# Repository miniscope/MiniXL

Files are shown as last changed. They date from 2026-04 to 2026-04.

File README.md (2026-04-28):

# MiniXL — Miniscope Extra Large FOV

The MiniXL is the second generation of the MiniLFOV, a large field-of-view miniature microscope for imaging neuronal activity in freely moving mice and larger animals. It supports deep brain imaging using implanted optical probes and cortical imaging through cranial windows.

## Features

- 3.5 mm field of view
- ~3 um resolution
- 1.9 mm working distance
- +/-200 um electronic focal adjustment
- Modular, achromatic optics
- 3.5 grams
- 30 mm tall
- Absolute head orientation sensor
- Single coaxial cable (down to 0.3 mm diameter) for power, communication, and data
- No soldering required

## Repository Structure

```
pcb/                PCB designs (KiCad)
  rigid-flex/       Main rigid-flex PCB assembly
    fabrication/    Gerber and drill files for manufacturing
optics/             Optical design (Zemax) source files
  plots/            Standardized output plots (MTF, spot diagrams, etc.)
housing/            3D printed microscope body
baseplate/          Head-mount baseplate
assets/             Images and resources for documentation
wiki.yml            Top-level metadata; per-component wiki.yml files in each subdir
                    are picked up by wiki-repo-bridge and synced on release tags.
```

## How to Cite

If you use the MiniXL in your research, please cite:

> Zhao, P., Guo, C., Xie, M., Chen, L., Golshani, P., & Aharoni, D. MiniXL: An open-source, large field-of-view epifluorescence miniscope enabling single-cell resolution and multi-region imaging in mice. *Science Advances*, 11(24), eads4995, 2025. DOI: [10.1126/sciadv.ads4995](https://doi.org/10.1126/sciadv.ads4995)

A BibTeX entry is available in [CITATION.bib](CITATION.bib).

## License

See [LICENSE](LICENSE) for details.

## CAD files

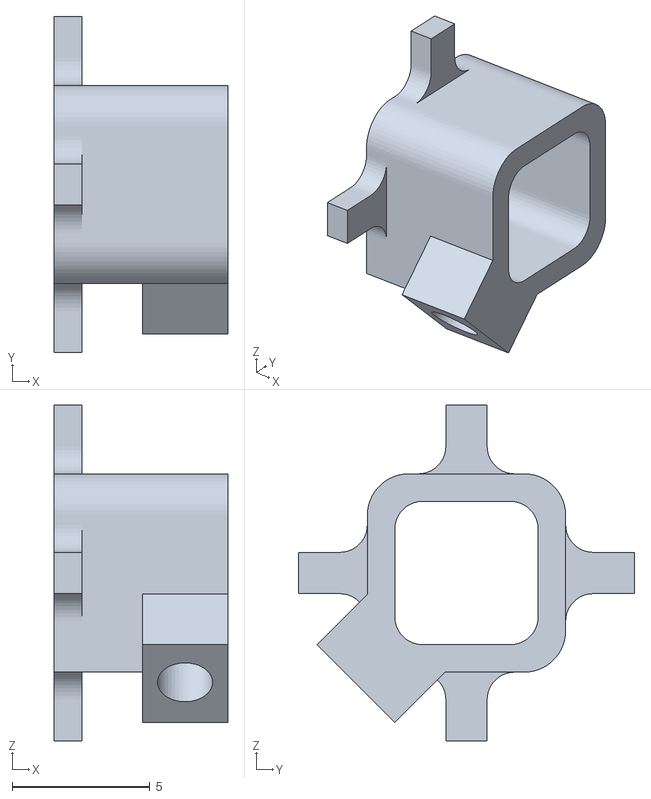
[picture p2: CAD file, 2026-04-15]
baseplate/fabrication/MiniXL_baseplate.stl
6.30 x 12.2 x 12.2

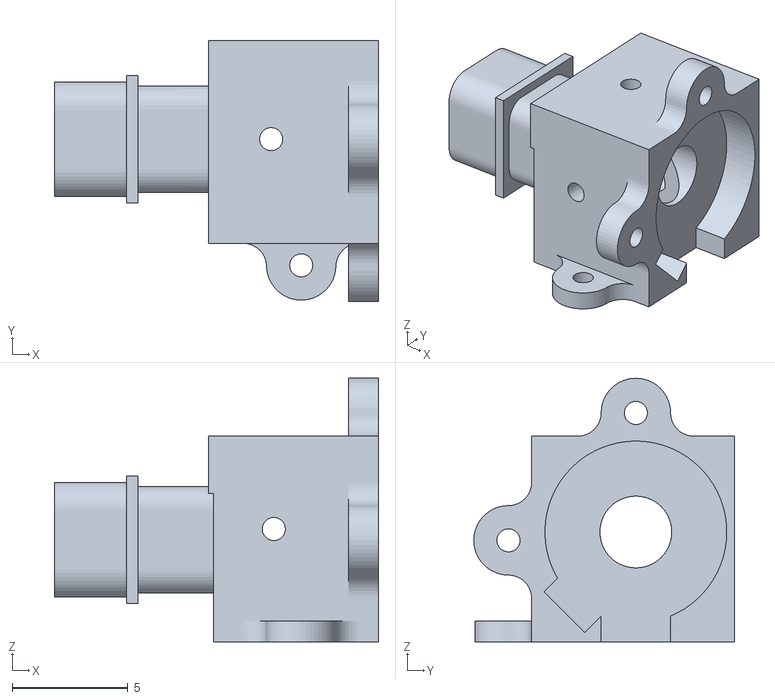
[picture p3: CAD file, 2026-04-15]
housing/fabrication/MiniXL_bottom.stl
14.0 x 11.2 x 11.4

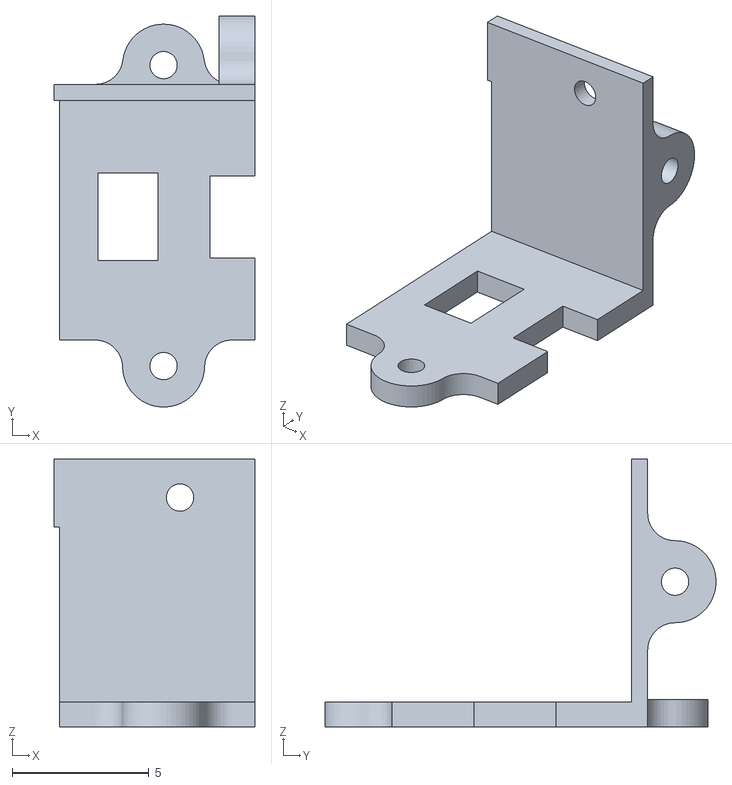
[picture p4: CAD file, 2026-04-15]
housing/fabrication/MiniXL_side.stl
7.33 x 14.3 x 9.78

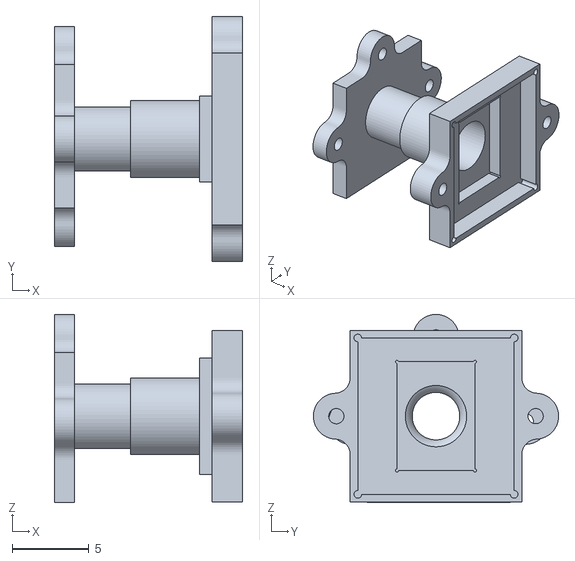
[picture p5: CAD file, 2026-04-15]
housing/fabrication/MiniXL_top.stl
12.3 x 16.0 x 12.3

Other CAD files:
baseplate/MiniXL_baseplate.f3d
housing/MiniXL_bottom.f3d
housing/MiniXL_side.f3d
housing/MiniXL_top.f3d

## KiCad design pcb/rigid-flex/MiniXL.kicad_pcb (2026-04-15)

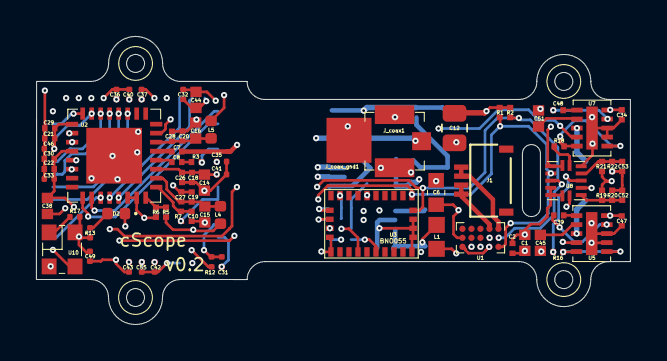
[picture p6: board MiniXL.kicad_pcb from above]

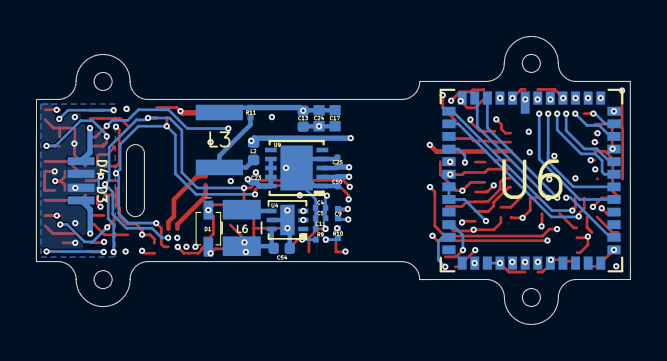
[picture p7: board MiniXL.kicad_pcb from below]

Board: 4 copper layers, 33.0 x 16.0 mm, 99 parts (24 on the bottom side), 56 nets.

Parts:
C1, C14, C15, C45, C51: GRM155R60J475ME87D; C_0402_1005Metric_L
C2, C5, C7, C9, C11, C18, C19, C20, C21, C22, C52, C53: GRM033R61A104ME15D; C_0201_0603Metric_L
C4, C26, C27, C28, C29, C30: GRM033R71A103KA01D; C_0201_0603Metric_L
C6: GRJ188R72A104KE11D; C_0603_1608Metric_L
C8: GRM033R61C473KE84D; C_0201_0603Metric_L
C10: GRM033R61A105ME15D; R_0201_0603Metric_ERJ_L
C12: GRM21BR61A476ME15L; C_0805_2012Metric_L
C13, C38: 10uF; C_0402_1005Metric_L
C16, C17, C24, C44: GRM155R60J106ME15D; C_0402_1005Metric_L
C23, C25, C31, C32, C33, C50: 1uF; C_0201_0603Metric_L
C34, C39, C47, C48: GRM033R61A225ME47D; C_0201_0603Metric_L
C35, C36, C37, C40, C41, C42, C43, C46, C55: 0.1uF; C_0201_0603Metric_L
C49: 10nF; C_0201_0603Metric_L
C54: 22uF; C_0402_1005Metric_L
D1: BAS316-TP; SOD_323_250X125X110L30X32L
D2: LED 0402; LED_0402_1005Metric
D3, D4: LXZ1-PB01; LED_LXZ1_PR01_L
H3, H3#2, H3#3, H3#4: MountingHole; Conn_1x1_700_Circular_Pad_mountinghole
J1: FH19C-4S-0.5SH(10)
J_coax1: U.FL-R-SMT-1(10); Coax_Conn_U.FL
J_coax_gnd1: Conn_01x01; Conn_1x1_100x100_Pad
L1: LQM18PN3R3MGHD; L_0603_1608Metric_L
L2, L4, L5: BLM15HD102SN1D; L_0402_1005Metric
L3: ADL3225V-470MT-TL000; L_1210_3225Metric_L
L6: LQM2HPN1R0MG0; L_1008_2520Metric_L
R1, R2: ERJ-1GNF3321C; R_0201_0603Metric_ERJ_L
R3: ERJ-1GNF49R9C; R_0201_0603Metric_ERJ_L
R5, R7, R9, R10, R16: ERJ-1GNF1022C; R_0201_0603Metric_ERJ_L
R6: ERJ-1GNF1003C; R_0201_0603Metric_ERJ_L
R11: ERJ-1GNF1801C; R_0201_0603Metric_ERJ_L
R12: 1k; R_0201_0603Metric_ERJ_L
R13: 500; R_0201_0603Metric_ERJ_L
R17: DNL; R_0201_0603Metric_ERJ_L
R18: ERJ-1GEF1022C; R_0201_0603Metric_ERJ_L
R19, R21: ERJ-1GNJ622C; R_0201_0603Metric_ERJ_L
R20, R22: ERJ-1GNF3741C; R_0201_0603Metric_ERJ_L
U1: MAX14574EWL+; BGA_15_NP50_3X5_155X255X69B31N
U2: DS90UB913ATRTVTQ1; QFN_33_P50_500X500X80L40X24T310L
U3: BNO055; LGA28R50P4X10_380X520X100
U4: SC189ZULTRT; SON_7P50_200X200X57L35X24T170X80N
U5, U7: LTC3218; SON_11_P50_300X200X80L40X25T239X64L
U6: MT9P031I12STM-DP; iLCC48P70_1000X1000X135L80X40N
U8: TPL0102-100RUCR; QFN_14_P40_200X200X40L40X20L
U9: NCV8154MW180280TBG; DFN10_3x3_11P50_300X300X100L40X24T250X180N
U10: SG-210STF 66.6667ML3; OSC_CC250X200X80L70X75L

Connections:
+3V3: C1.1, C2.1, C4.1, C5.1, C9.2, C12.1, C23.1, C34.1, C47.1, C54.1, L1.1, L6.2, R1.2, R2.2, R9.1, R10.1, R19.1, R21.1, U1.A3, U1.B2, U3.3, U3.28, U4.6, U5.10, U7.10, U8.14, U9.7, U9.8, U9.9, U9.10
+5V: C13.1, C17.1, C24.1, L3.2, R11.1, U4.2, U4.3
/CAP: C11.2, U3.9
/ENT: U2.15, U5.4, U7.4
/EWL1: J1.1, J1.2, U1.C2
/EWL2: J1.3, J1.4, U1.C1
/EXTCLK: U6.31, U10.3
/RESET_BAR: C31.1, R12.2, U6.16
/Va: C52.1, R19.2, R20.1, U8.1
/Vb: C53.1, R21.2, R22.1, U8.4
/_Wa: R16.1, U8.3
/_Wb: R18.1, U8.6
CLK_OUT: U2.3, U6.32
DIN0: U2.19, U6.35
DIN1: U2.20, U6.36
DIN2: U2.21, U6.37
DIN3: U2.22, U6.38
DIN4: U2.23, U6.40
DIN5: U2.24, U6.41
DIN6: U2.26, U6.42
DIN7: U2.27, U6.43
DIN8: U2.29, U6.44
DIN9: U2.30, U6.45
DOUT_P: C7.1, J_coax1.2, L2.1
FV: U2.2, U6.7
GND: C1.2, C2.2, C4.2, C5.2, C6.2, C9.1, C10.2, C11.1, C12.2, C13.2, C14.2, C15.2, C16.2, C17.2, C18.2, C19.2, C20.2, C21.2, C22.2, C23.2, C24.2, C25.2, C26.2, C27.2, C28.2, C29.2, C30.2, C31.2, C32.2, C33.2, C34.2, C35.2, C36.2, C37.2, C38.2, C40.2, C41.2, C42.2, C43.2, C44.2, C45.2, C46.2, C47.2, C49.2, C50.2, C51.2, C52.2, C53.2, C54.2, C55.2, D2.1, D3.C, D4.C, J_coax1.1, J_coax_gnd1.1, R3.1, R6.2, R20.2, R22.2, U1.A2, U1.A5, U2.6, U2.7, U2.33, U3.2, U3.5, U3.6, U3.15, U3.16, U3.17, U3.18, U3.25, U4.5, U4.7, U5.7, U5.8, U5.11, U6.2, U6.3, U6.6, U6.10, U6.17, U6.20, U6.21, U6.22, U6.26, U6.46, U7.7, U7.8, U7.11, U8.2, U8.5, U8.7, U8.8, U8.11, U8.12, U8.13, U9.1, U9.4, U9.11, U10.2
I2C_SCL: R2.1, U1.B1, U2.4, U3.19, U6.4, U8.10
I2C_SDA: R1.1, U1.A1, U2.5, U3.20, U6.5, U8.9
LV: U2.1, U6.8
MODE: R5.2, R6.1, U2.8
unnamed: C6.1, D1.C, U1.B5
unnamed: C7.2, U2.13
unnamed: C8.1, R3.2
unnamed: C8.2, U2.12
unnamed: C39.1, U5.9
unnamed: C39.2, U5.1
unnamed: C45.1, U5.2
unnamed: C48.1, U7.9
unnamed: C48.2, U7.1
unnamed: C51.1, U7.2
unnamed: D1.A, L1.2, U1.A4
unnamed: D2.2, R13.1
unnamed: D3.A, U5.3
unnamed: D4.A, U7.3
unnamed: L2.2, L3.1, R11.2
unnamed: L6.1, U4.4
unnamed: R9.2, U3.11
unnamed: R10.2, U3.4
unnamed: R16.2, U5.5, U5.6
unnamed: R17.2, U10.1
unnamed: R18.2, U7.5, U7.6
PDB: C10.1, R7.2, U2.9
VDDCML: C16.1, C20.1, C28.1, L5.1, U2.14
VDDD: C14.1, C18.1, C22.1, C26.1, C30.1, C33.1, C36.1, C38.1, C41.1, C50.1, L4.2, L5.2, R5.1, U2.11, U2.28, U6.12, U6.47, U9.2
VDDIO: C21.1, C25.1, C29.1, C32.1, C35.1, C37.1, C40.1, C42.1, C43.1, C44.1, C46.1, C49.1, C55.1, R7.1, R12.1, R13.2, R17.1, U2.25, U6.1, U6.11, U6.13, U6.14, U6.23, U6.24, U6.25, U6.39, U6.48, U9.3, U10.4
VDDPLL: C15.1, C19.1, C27.1, L4.1, U2.10

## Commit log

2026-04-15 Port MiniXL design files and establish standardized repo structure
    Ported current design files from the old MiniXL repo and reorganized
    into a standardized structure intended to serve as the template for
    all miniscope hardware projects.
    Structure: pcb/ (KiCad rigid-flex + fabrication outputs), optics/
    (Zemax source + plots), housing/, baseplate/, holder/, assets/.
    Each component has a metadata.yml for future CI-driven wiki sync
    to miniscope.org.
    Note: Many files (names, library paths, design metadata) are still
    inconsistent and outdated from the previous repo. Cleaning these up
    is ongoing work.
    [Kicad_LFOV_RigidFlex_Assembly.sch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]
2026-04-15 Add CAD/STL files, move PCB into rigid-flex subdirectory
    Add housing CAD (body top/bottom/side) and baseplate with Fusion 360
    source files and STL exports in fabrication/ subdirectories. Move PCB
    files into pcb/rigid-flex/ to support multiple PCB designs. Images
    moved to assets/img/. Dates removed from STL filenames — git tracks
    versioning.
    [Kicad_LFOV_RigidFlex_Assembly.sch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]
2026-04-15 Upgrade KiCad project to v10, unify naming to MiniXL
    Opened legacy project in KiCad 10 and saved as MiniXL, which:
    - Upgrades schematic from legacy .sch to .kicad_sch format
    - Unifies project/schematic/PCB under a single MiniXL base name
    - Removes legacy cache, rescue, and netlist files
    - Removes old Screwhole2 variant .pro and .kicad_pcb
    Library tables still reference old paths and need migration to
    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
    [Kicad_LFOV_RigidFlex_Assembly.sch, Kicad_LFOV_RigidFlex_Assembly_Screwhole2.kicad_pcb, MiniXL.kicad_pcb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]
2026-04-27 Migrate metadata.yml to wiki.yml for repo->wiki CI integration
    Replaces the per-directory metadata.yml files with a wiki.yml schema
    that maps directly to the labki-ontology Project/Component/Release
    data model. CI on a tagged commit will read these files to produce
    versioned wiki pages.
    - Root wiki.yml declares kind: project with repository_url, license,
    predecessor (MiniLFOV), citation, specs, and features.
    - Each component subdir (housing, optics, pcb/rigid-flex, baseplate)
    has its own wiki.yml with kind: hardware_component, version,
    source_path, hardware_type, and design_files.
    - Adds a baseplate wiki.yml that was missing under the old metadata.yml
    scheme.
    - Drops the holder entr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
2026-04-28 Wire up wiki sync via wiki-repo-bridge
    - Adds .github/workflows/sync-to-wiki.yml — calls the reusable
    labki-org/wiki-repo-bridge sync workflow on every v* tag and via
    manual workflow_dispatch (defaulting to dry-run for safety). Inherits
    WIKI_REPO_BOT_USER / WIKI_REPO_BOT_PASSWORD from the miniscope org
    secrets.
    - Adds responsible_party: Aharoni Lab to wiki.yml so Release pages
    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
2026-04-28 Pre-sync cleanup: README structure, PCB specs format
    - README pointed at metadata.yml (renamed long ago) and a holder/ dir that
    doesn't exist; updated to reflect per-component wiki.yml files.
    - pcb/rigid-flex/wiki.yml had bare layers/substrate keys that don't map to
    wiki properties; moved into specs: array to silence validator warnings.
2026-04-28 Change hardware type from PCB to Circuit Board
2026-05-19 Sync to miniscope.org wiki with separate bot credentials
    The miniscope.org wiki uses a different bot account than the aharoni-lab
    wiki, so map WIKI_REPO_MINISCOPE_BOT_USER/PASSWORD to the bridge's
    alt-credentials slot (added in labki-org/wiki-repo-bridge#1) via the
    `creds=alt` annotation.
    Note: requires labki-org/wiki-repo-bridge#1 to be merged to main before
    this workflow can run successfully — the reusable workflow rejects
    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
